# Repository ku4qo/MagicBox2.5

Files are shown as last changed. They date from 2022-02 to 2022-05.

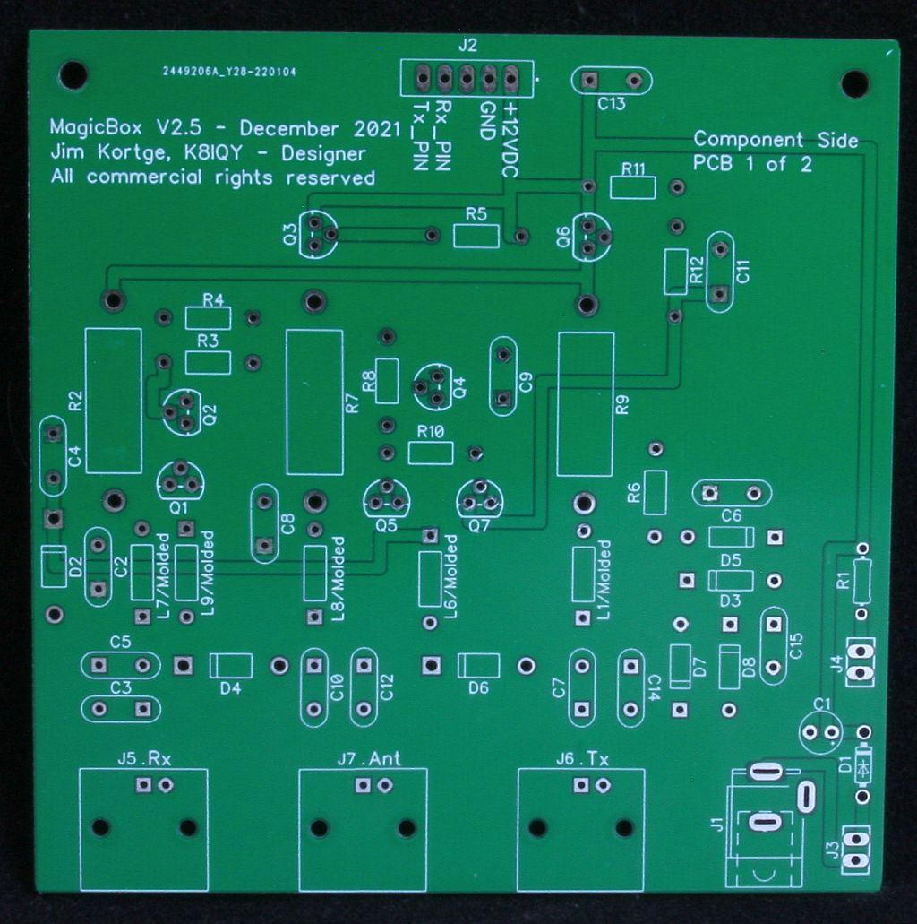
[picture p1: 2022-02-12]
images/MagicBoxV2.5-PCB1-1024pix.jpg

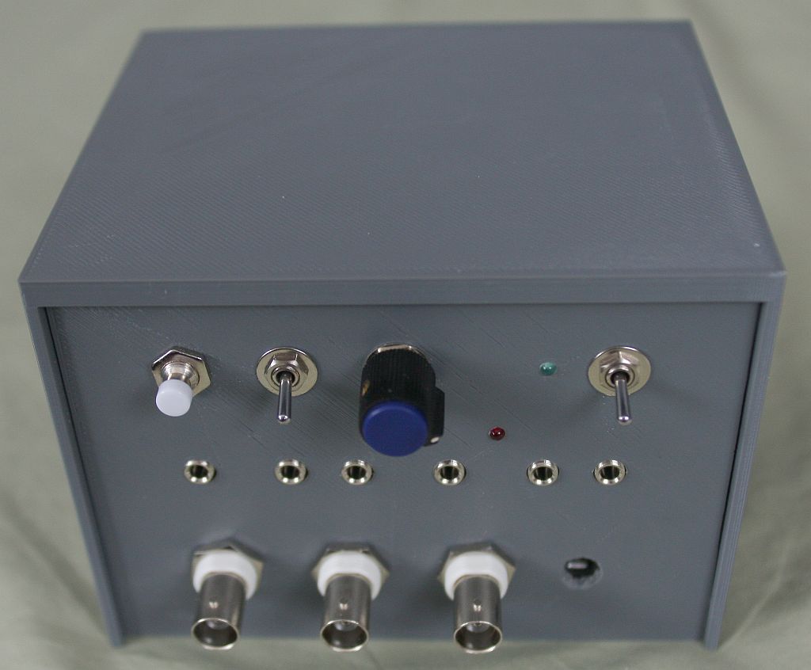
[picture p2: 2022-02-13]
images/MagicBoxV2.5_Front_1024pix.jpg

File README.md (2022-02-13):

# MagicBox2.5
Repo for software and hardware for the MagicBox 2.5 Tx/Rx interface 

The K8IQY/KU4QO MagicBox V2.5, is an updated version of the project
designed by K8IQY in 2013 and kitted by the 4 State QRP group. In the prior
version, the MagicBox could be used to connect a receiver and a transmitter
together to operate as a transceiver, with all of the RF switching and Audio Muting
handled by the MagicBox. It used a programmed microprocessor to control the
functions within the box.
The updated version provides all of the RF Switching and Audio Muting
functionality of the original, along with addition of an internal, speed adjustable,
CW Keyer, power control for transmitters requiring an external power source to be
switched, such as a Tuna Tin 2, and a redesign of the PIN diode RF Switching
circuitry to handle higher transmitter power levels. This version should handle
transmitters below 20 watts, with very low loss.

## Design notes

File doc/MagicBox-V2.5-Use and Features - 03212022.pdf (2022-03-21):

### K8IQY/KU4QO MagicBox V2.5 - Use and Features

### Jim Kortge, K8IQY Mike Maiorana, KU4QO

The K8IQY/KU4QO MagicBox V2.5, is an updated version of the project designed by K8IQY in 2013 and kitted by the 4 State QRP group. In the prior version, the MagicBox could be used to connect a receiver and a transmitter together to operate as a transceiver, with all of the RF switching and Audio Muting handled by the MagicBox. It used a programmed microprocessor to control the functions within the box.

The updated version provides all of the RF Switching and Audio Muting functionality of the original, along with addition of an internal, speed adjustable, CW Keyer, power control for transmitters requiring an external power source to be switched, such as a Tuna Tin 2, and a redesign of the PIN diode RF Switching circuitry to handle higher transmitter power levels. This version has been tested up to 20 watts, with very low loss.

Two printed circuit boards are employed in this version. The first one contains the power conditioning circuitry for the system, the PIN diode RF Switching circuitry for both the connected transmitter and receiver, and connections to the second printed circuit board. On the second board is where the system control microprocessor lives, the keying circuits for both negative (ground to transmit) and positive (source keyed) powered transmitters, and the receiver audio muting and side tone injection circuits. Unlike the previous version, the microprocessor in this version is an Arduino Nano (or clone) that is programmed by the builder (using the Arduino IDE) and the underlying control code can be modified to implement desired changes or additional functionality.

All of the documentation lives on GitHub, allowing anyone to procure printed circuit boards using the supplied Gerber files, have full access to the control software, and have access to the design’s schematic diagrams, bill of materials, and even suggested sources for the parts used.

“As built” Prototype Specifications:

Receiving
Antenna port to receive port loss: ~0.25 dB maximum
Receive port to transmit port isolation: -40 to -20 dB, frequency dependent

Transmitting
Transmit port to antenna port loss: ~0.25 dB maximum
Transmit port to receive port isolation: -70 to -50 dB, frequency dependent

Transmitter power limit – Tested at 20 Watts CW for 10 seconds, 10 Watts for 1 minute

Keyer
QSK and SemiQSK operation, user selected by internal jumper
Keying speeds from 5 to 35 WPM, user adjustable
via a speed set potentiometer
Straight key operation below 5 WPM

Keying of transmitters requiring grounding of key line, up to 100 volts
Keying of transmitters requiring power to be applied up to 48 volts and 2 amperes

Audio
Receive audio port to speaker port isolation: ~90+ dB
Side tone injection (level adjustable) into receive audio chain during transmit “Spot” function to zero receiver to transmitter frequency

Power Requirements (12 volt supply)
Receiving - 110 milliamperes
Transmitting - 160 milliamperes

How to use the MagicBox V2.5

This is a short discussion highlighting the features of the MagicBox V2.5 and how to hook it up to your receiver and transmitter.

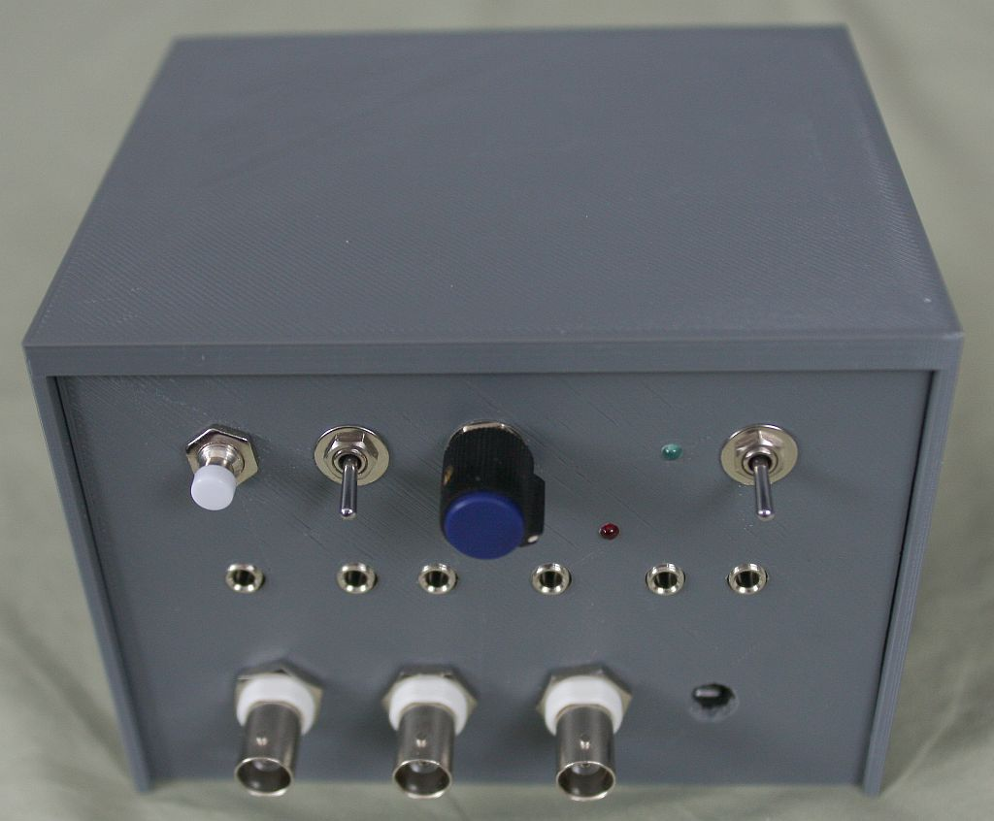
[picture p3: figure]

Starting at the lower left of this photo, the 1st BNC connector is the antenna input to your receiver. The 2nd BNC connector is where you connect your antenna. Lastly, the 3rd BNC connector goes to the output of your transmitter. When in “receive mode”, the center antenna connector is connected to the leftmost BNC, supplying signals to your receiver. When in “transmit mode”, the leftmost BNC is disconnected from the antenna, and shorted to ground, and the rightmost BNC is connected through to the center BNC, so that your transmitter is connected to your antenna. 1N4007 diodes are used as PIN diodes to do that signal steering, and their sequencing is done by the Arduino Nano

Figure 1: MagicBox V2.5 Font Panel board. Power to the system (12 to 13.8 volts DC) connects to the 2.1mm X 5.5mm power connector to the right of the BNC connectors.

The next row of connectors, above the BNCs, are all 1/8 inch, stereo jacks used for external signals, both inputs and outputs. The 1st of these on the left is the input connector for your paddle, or straight key. If using a paddle, the tip is “DIT”, the ring is “DAH”, and the sleeve is the common or ground. Either the tip or ring can be used for a straight key along with the ground.

The next two connectors are used for receive audio control. Audio FROM your receiver is connected to the leftmost of this pair, with the tip being the “HOT” lead and the ring being the ground. Audio TO your speaker or headphones connects to the rightmost of this pair. The “HOT” lead of your speaker goes to the Tip and the ground goes to the ring. Stereo headphones plug in directly. Note: the barrels of these two connectors can not be grounded. If mounting the MagicBox in a metal box, shrink tubing should be placed on the barrel of each of these two connectors. A non-conducting, 3D printed box is suggested.

The next 3 connectors are for keying your transmitter. If your transmitter is keyed by grounding a line, such as a “Keyline” in a solid state transmitter, or an older cathode keyed rig, where the “Keyline” has a positive voltage on it and needs to be grounded to key the transmitter “ON”, this is the connector to use. The tip is the “HOT” lead with the sleeve being the ground.

If you are using a transmitter, like a Tuna Tin Two, where the transmitter is keyed by keying the supply line, use the next pair of connectors. Connect the power supply for the transmitter to the right most of this pair, with the tip being the “HOT” lead, and the sleeve being the ground. Keyed voltage to your transmitter is available from the leftmost connector of this pair. The tip is the “HOT” lead and the ground is on the sleeve.

The red LED between the 4th and 5th connector lights when the transmitter is keyed, regardless of the keying setup used, as detailed above.

The leftmost push button on the upper level has two functions. With a “short press” a readout of the current CW speed is sent to the audio chain; a “long press”, turns on the transmitter for 10 seconds for “tune up”. A second push while the “tune up” function is engaged, terminates that function. Next is a SPST toggle switch used to implement the spotting function, where audio from the muted receiver is selectively mixed with the system generated side tone so that the receiver and transmitter can be set to the same frequency.

Next is a potentiometer, used to set the CW speed. When the potentiometer is set below 5 WPM, straignt key mode is automaticallyenabled.

A green LED is used to indicate when power is applied to the system, and to the right of it is a SPST toggle switch used to turn on – turn off system power.

All of the connections described are clearly shown on the schematics and are labeled on the two PC Boards used in this system. Some study of these resources is suggested for a complete understanding of how the system functions.

Miscellanous Parts
Below are some sources that I used for the parts in this prototype build. They may or may not be available, as parts on Amazon come and go.

Spacers
<https://www.amazon.com/gp/product/B06Y5TJXY1/ref=ppx_yo_dt_b_asin_title_o05_s00?ie=UTF8&psc=1> (https://www.amazon.com/gp/product/B06Y5TJXY1/ref=ppx_yo_dt_b_asin_title_o05_s00?ie=UTF8&psc=1)

This photo shows how spacers in this set are used.

Arduino Nano Clone

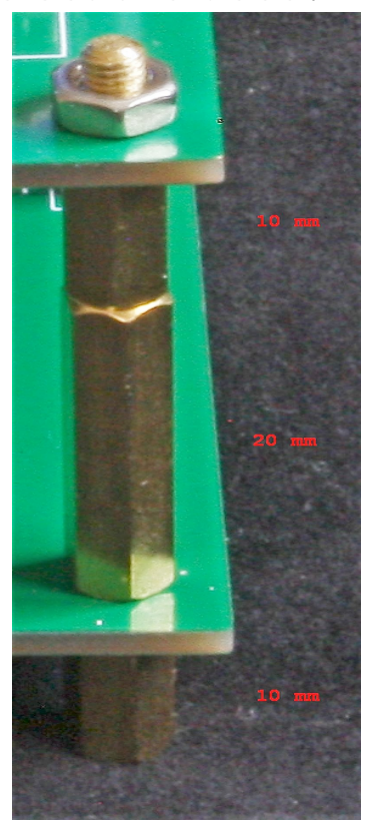
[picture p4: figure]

<https://www.amazon.com/gp/product/B0713XK923/ref=ppx_yo_dt_b_asin_title_o04_s00?ie=UTF8&psc=1> (https://www.amazon.com/gp/product/B0713XK923/ref=ppx_yo_dt_b_asin_title_o04_s00?ie=UTF8&psc=1)

Dupont Connectors (10 cm, Female-Female) <https://www.amazon.com/gp/product/B07GD312VG/ref=ppx_yo_dt_b_asin_title_o09_s00?ie=UTF8&th=1> (https://www.amazon.com/gp/product/B07GD312VG/ref=ppx_yo_dt_b_asin_title_o09_s00?ie=UTF8&th=1)

Case 3D Printing Filament
<https://www.amazon.com/gp/product/B08BXLQ26X/ref=ppx_yo_dt_b_asin_title_o00_s00?ie=UTF8&psc=1> (https://www.amazon.com/gp/product/B08BXLQ26X/ref=ppx_yo_dt_b_asin_title_o00_s00?ie=UTF8&psc=1)

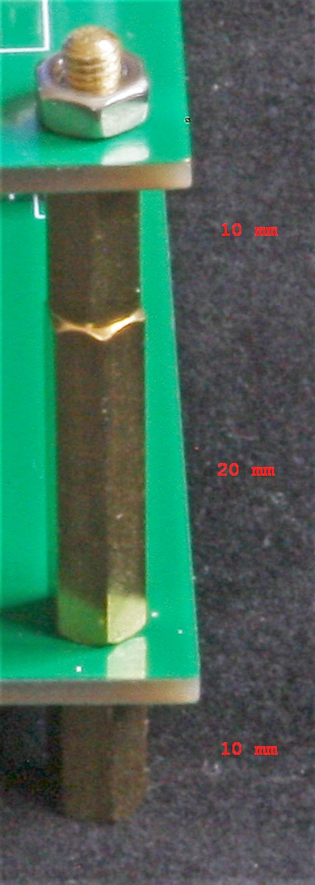
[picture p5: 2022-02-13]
images/Spacers-edited.jpg

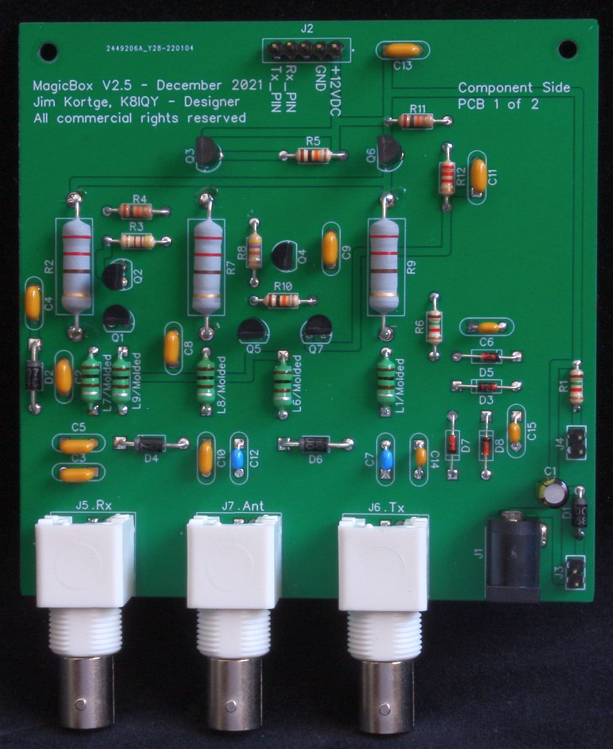
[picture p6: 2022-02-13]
images/MagicBoxV2.5-PCB1_Stuffed-1024pix.jpg

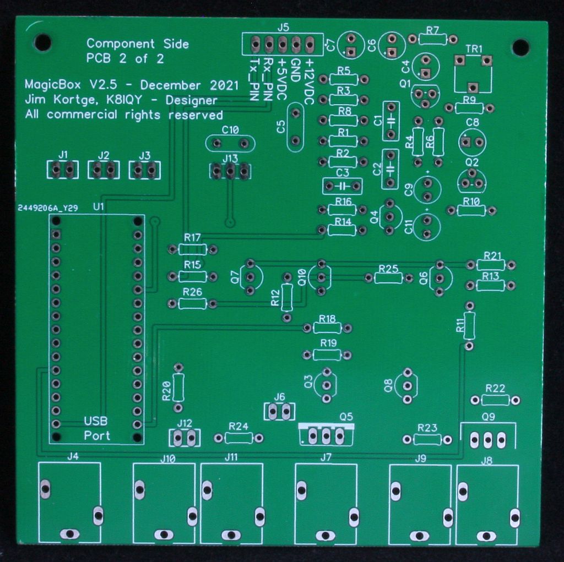
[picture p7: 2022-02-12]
images/MagicBoxV2.5-PCB2-1024pix.jpg

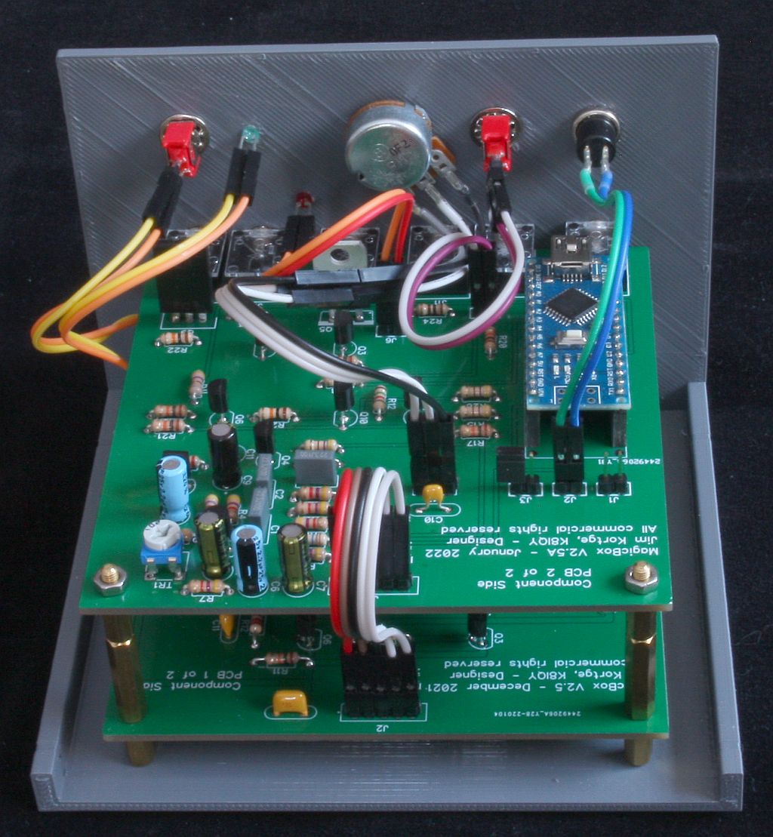
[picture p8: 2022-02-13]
images/MagicBoxV2.X_Rear_1024pix.jpg

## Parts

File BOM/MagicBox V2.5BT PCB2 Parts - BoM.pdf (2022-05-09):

# RefDes | Quantity Value | Name | Manufacturer/Source | Part Number

1 C10 | 1 | 0.01uF | MLCC | Tayda Electronics | A-1366
2 C1, C2, C3 | 3 | 0.022uF | Mylar Capacitor | Tayda Electronics | A-4107
3 C5 | 1 | 0.1uF | MLCC | Tayda Electronics | A-214
4 C6, C8 | 2 | 2.2uF | 25 VDC Electrolytic Tayda Electronics | A-4510
5 C4, C7, C9 | 3 | 47uF | 25 VDC Electrolytic Tayda Electronics | A-5713
6 J12 | 1 | Spot | 2-pin header | Tayda Electronics | A-4662
7 J1 | 1 | Spd_Up | 2-pin header | Tayda Electronics | Part of above
8 J2 | 1 | Spd_Dwn | 2-pin header | Tayda Electronics | Part of above
9 J3 | 1 | Non-QSK | 2-pin header | Tayda Electronics | Part of above
10 J6 | 1 | Tx-LED | 2-pin header | Tayda Electronics | Part of above
11 J13 | 1 | Speed Pot | 3-pin header | Tayda Electronics | Part of above
12 J5 | 1 | Interconnect | 5-Pin Header | Tayda Electronics | Part of above
13 J4 | 1 | Paddle | PCB Phone Jack | Tayda Electronics | A-069
14 J7 | 1 | TxKey_GND | PCB Phone Jack | Tayda Electronics | A-069
15 J8 | 1 | TxKey_PWR_IN | PCB Phone Jack | Tayda Electronics | A-069
16 J9 | 1 | TxKey_PWR_OUT PCB Phone Jack | Tayda Electronics | A-069
17 J10 | 1 | Rx_Audio_In | PCB Phone Jack | Tayda Electronics | A-069
18 J11 | 1 | Spkr/Phones | PCB Phone Jack | Tayda Electronics | A-069
19 Q1, Q2 | 2 | PN2222A | NPN Transistor | Tayda Electronics | A-096
20 Q3, Q4, Q6, Q7, Q8, Q10 | 6 | BS170 | BS170 | Tayda Electronics | A-096
21 Q5 | 1 | IRF510 | N-MOSFET | Tayda Electronics | A-088
22 Q9 | 1 | FQPF11P06 | P-MOSFET | Tayda Electronics (IRF9640 Sub) | A-084
23 R24 | 1 | 100 | 1/4 Watt Resistor | Tayda Electronics | A-2245
24 R10 | 1 | 220 | 1/4 Watt Resistor | Tayda Electronics | A-2246
25 R6, R11, R14, R15, R18, R26 | 6 | 470 | 1/4 Watt Resistor | Tayda Electronics | A-2247
26 R12 | 1 | 1.5K | 1/4 Watt Resistor | Tayda Electronics | A-2202
27 R1, R2, R4, R5, R7, R8, R9 | 7 | 4.7K | 1/4 Watt Resistor | Tayda Electronics | A-2310
28 R13, R16, R17, R19, R20, R21, R22, R23, R25 9 | 10K | 1/4 Watt Resistor | Tayda Electronics | A-2203
29 R3 | 1 | 36K | 1/4 Watt Resistor | Tayda Electronics | A-2773
33 TR1 | 1 | 1K | 6 mm trimmer | Tayda Electronics | A-2509
34 External J13 connection | 1 | 1K | 1-turn potentiometer Tayda Electronics | A-4870
35 U1 | 1 | Arduino Nano V3.X A000005 | Tayda Electronics (Amazon - ELEGOO Nano Board) A-2864
36 Misc part | 1 | Arduino mounting | 40-pin female header Tayda Electronics | A-196
37 Misc part | 2 | Speed select switch SPST-momentary | Tayda Electronics | A-5051
38 C11 | 1 | Value as needed | 25 VDC Electrolytic 2.2uF suggested value

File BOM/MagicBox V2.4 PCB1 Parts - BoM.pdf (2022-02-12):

# RefDes | Quantity Value | Name | Manufacturer/Source | Part Number

1 C14 | 1 | 100pF | NP0 Ceramic Capacitor Mouser | 810-FA28NP02A101JNU6
2 C6, C15 | 2 | 0.01uF | MLCC | Tayda Electronics | A-1366
3 C2, C3, C4, C5, C8, C9, C10, C11, C13 | 9 | 0.1uF | MLCC | Tayda Electronics | A-5705
4 C7, C12 | 2 | 1uF | X7S Ceramic Capacitor Mouser | 810-FG24X7S2A105KRT0
5 C1 | 1 | 47uF | 25 VDC Electrolytic | Tayda Electronics | A-5713
6 D1 | 1 | 1N5817/8 | Schottky Diode | Tayda Electronics | A-159
7 D2, D4, D6 | 3 | 1N4007 | Si Diode | Tayda Electronics | A-155
8 D3, D5, D7, D8 | 4 | 1N914 | Si Diode | Tayda Electronics | A-615
9 J1 | 1 | 12 Volts | Power Jack 2.1mm | Tayda Electronics | A-4118
10 J2 | 1 | Interconnect 5-Pin Header | Tayda Electronics | A-197
11 J3 | 1 | Pwr Switch | 2-pin header | Tayda Electronics | Part of A-197
12 J4 | 1 | Pwr LED | 2-pin header | Tayda Electronics | Part of A-197
13 J5 | 1 | Rx_Input | BNC Connector | TE Connectivity (Mouser) 571-2269901
14 J6 | 1 | Tx_Input | BNC Connector | TE Connectivity (Mouser) 571-2269901
15 J7 | 1 | Antenna | BNC Connector | TE Connectivity (Mouser) 571-2269901
16 L1/Molded, L6/Molded, L7/Molded, L8/Molded, L9/Molded 5 | 100uH | Molded Inductor | Tayda Electronics | A-193
17 Q1, Q2, Q4, Q5, Q7 | 5 | BS170 | MOSFET | Tayda Electronics | A-096
18 Q3, Q6 | 2 | PN2907A | PNP Transistor | Tayda Electronics | A-108
19 R2, R7, R9 | 3 | 220/2W | Metal Film Resistor | Tayda Electronics | A-2538
20 R3, R8 | 2 | 470 | 1/4 Watt Resistor | Tayda Electronics | A-2247
21 R1, R6 | 2 | 1.5k | 1/4 Watt Resistor | Tayda Electronics | A-2202
22 R12 | 1 | 2.2k | 1/4 Watt Resistor | Tayda Electronics | A-2341
23 R4, R5, R10, R11 | 4 | 10k | 1/4 Watt Resistor | Tayda Electronics | A-2203
24 Misc. part | 6 | 2-56 X 1/4 | Self Tapping Screw | McMaster-Carr | 94629A110

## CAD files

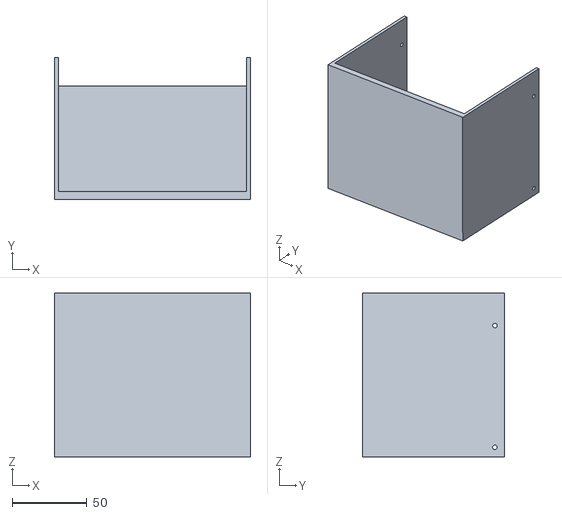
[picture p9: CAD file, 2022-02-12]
case/MagicBox-Cover-V5_K8IQY.stl
130.8 x 94.7 x 109.2

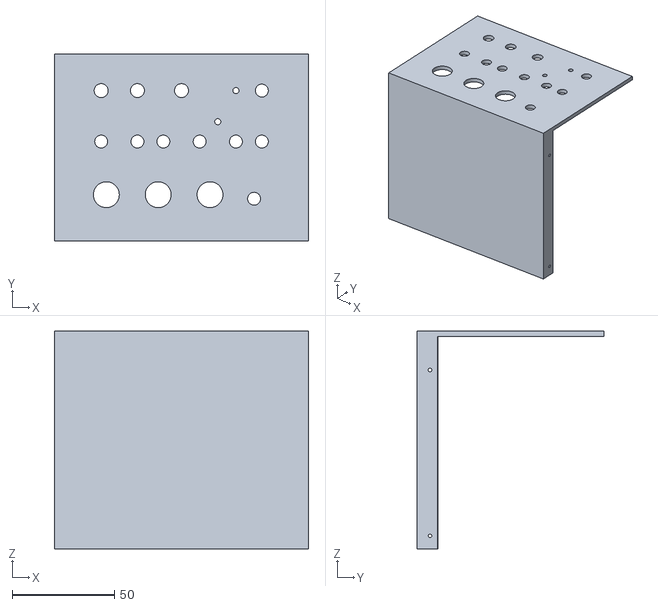
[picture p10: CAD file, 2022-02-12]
case/MagicBox-FrontPanel-V5_K8IQY.stl
124.5 x 91.6 x 106.7

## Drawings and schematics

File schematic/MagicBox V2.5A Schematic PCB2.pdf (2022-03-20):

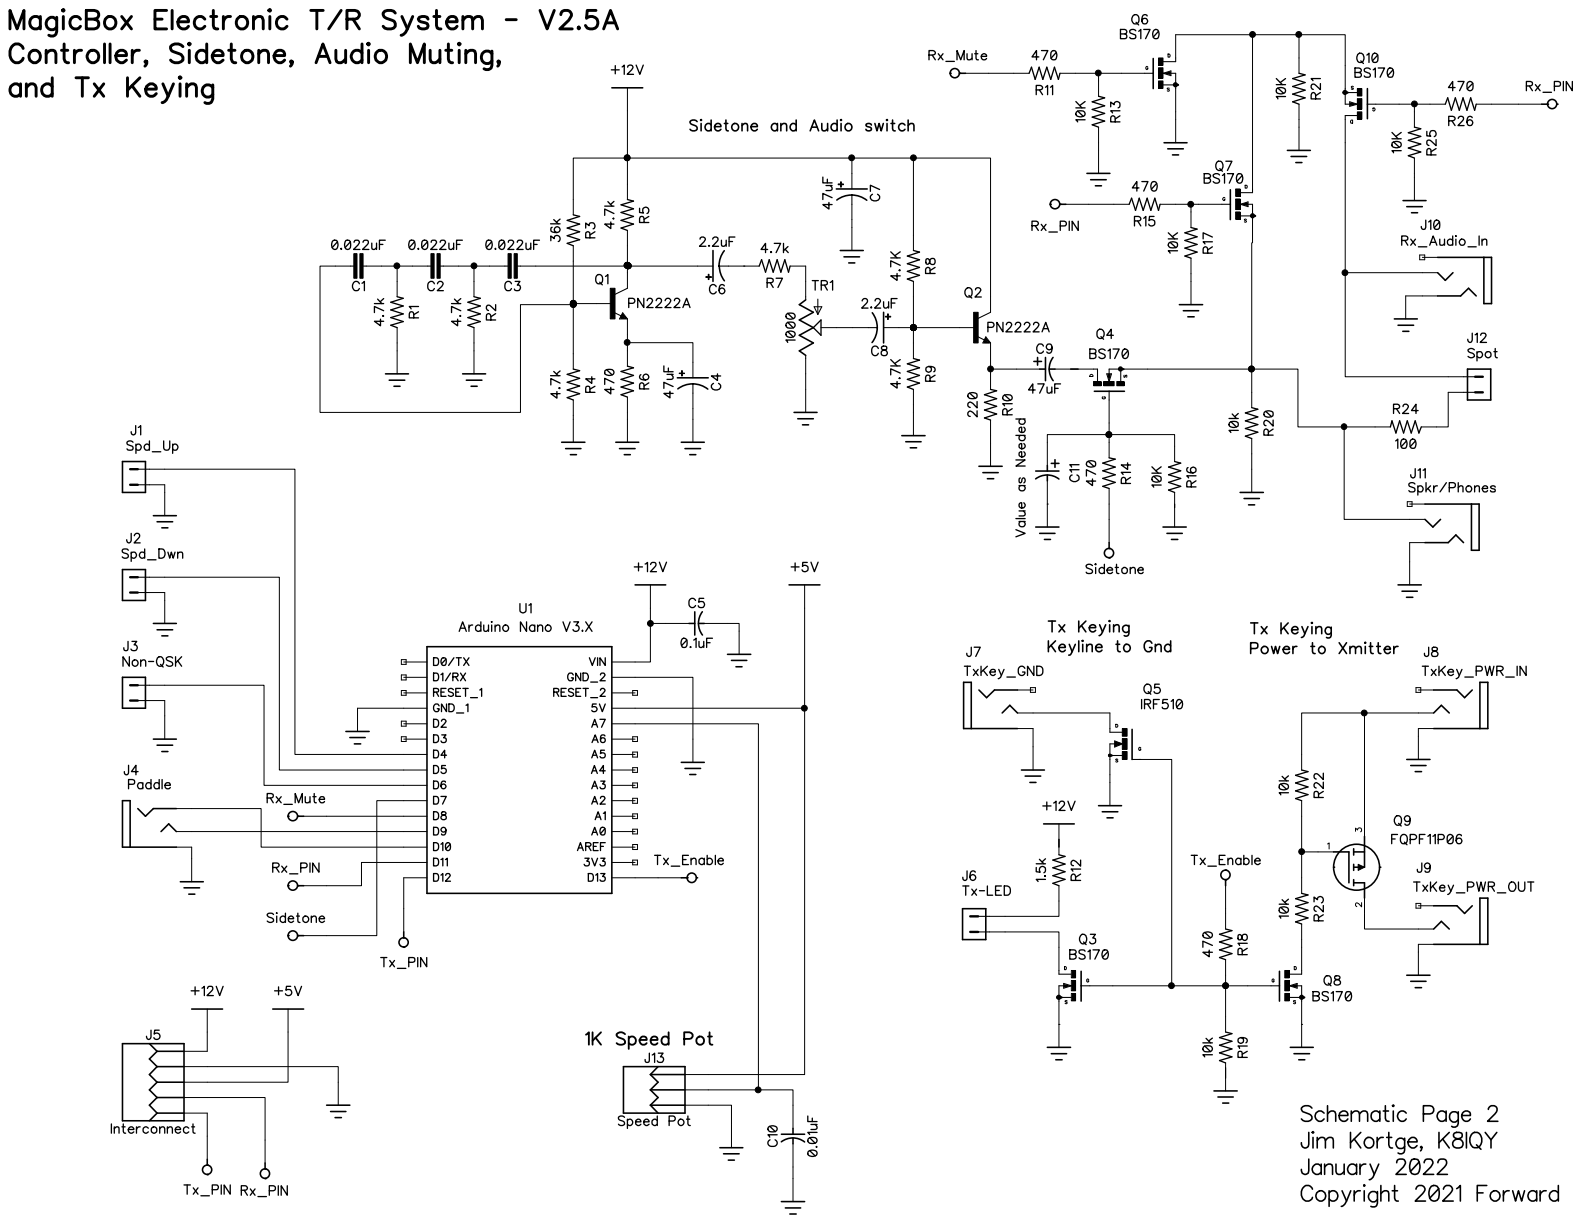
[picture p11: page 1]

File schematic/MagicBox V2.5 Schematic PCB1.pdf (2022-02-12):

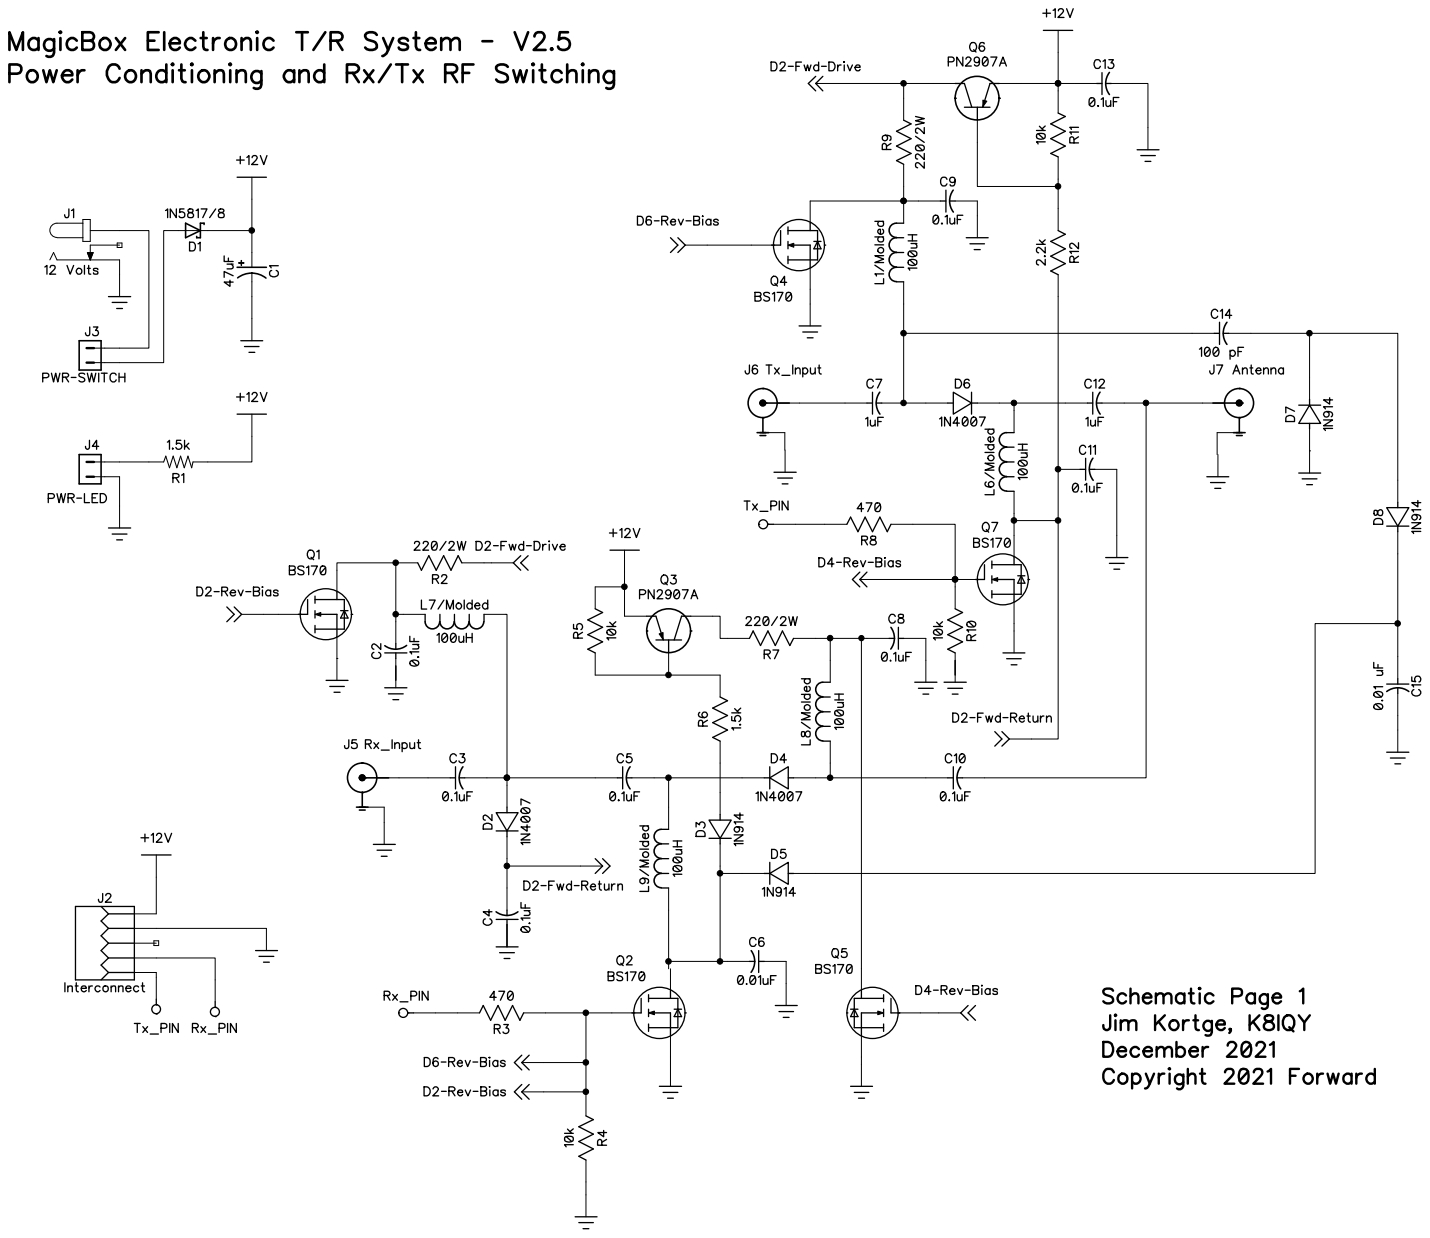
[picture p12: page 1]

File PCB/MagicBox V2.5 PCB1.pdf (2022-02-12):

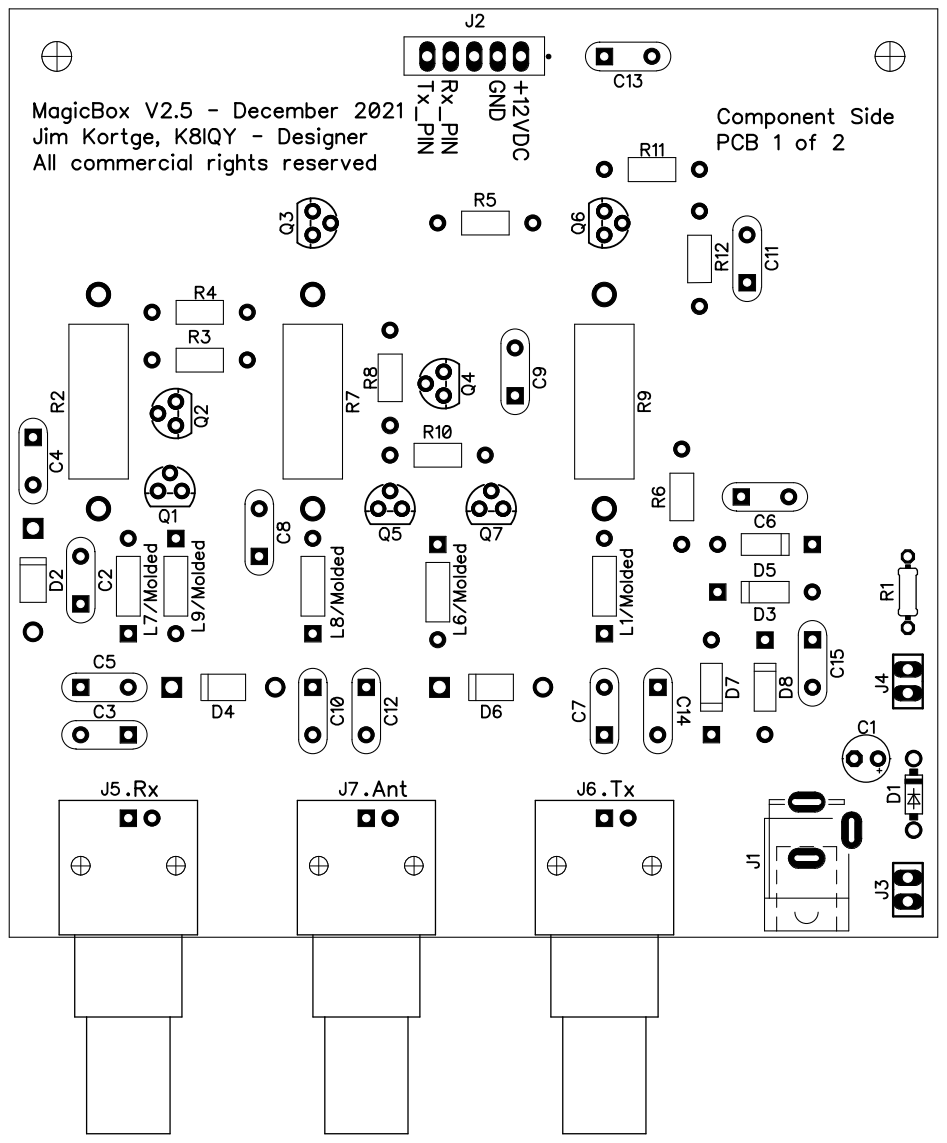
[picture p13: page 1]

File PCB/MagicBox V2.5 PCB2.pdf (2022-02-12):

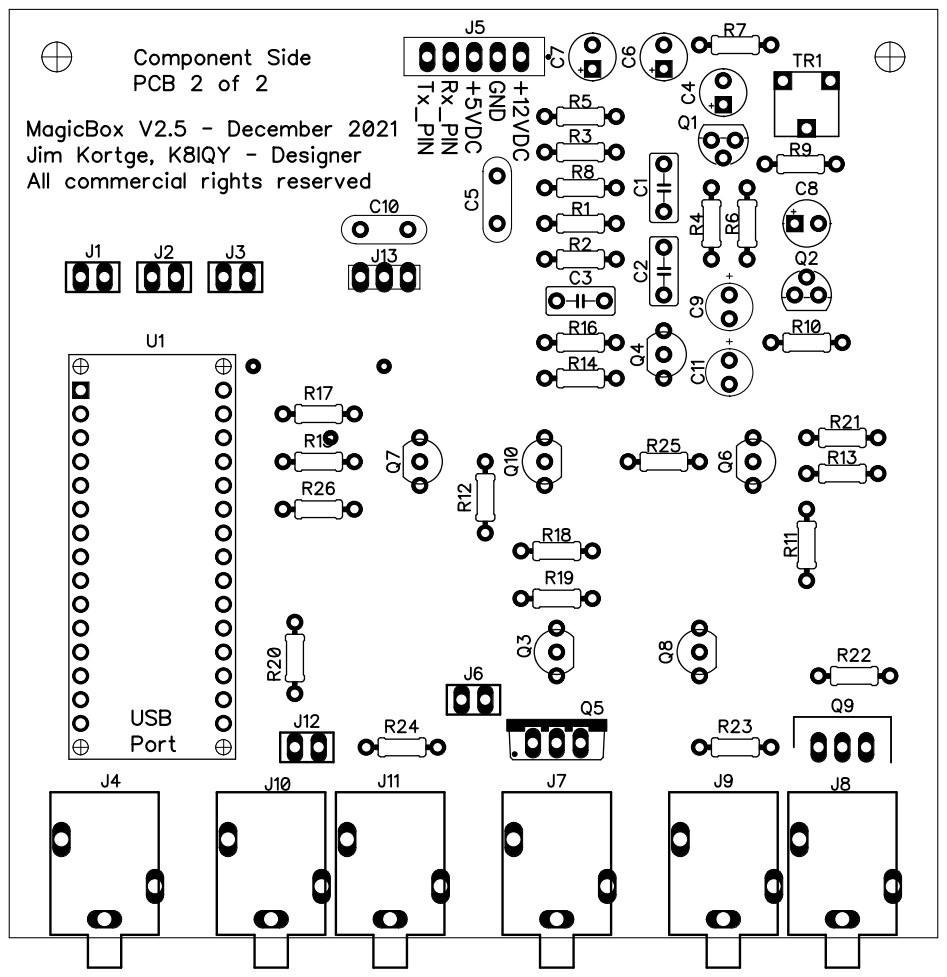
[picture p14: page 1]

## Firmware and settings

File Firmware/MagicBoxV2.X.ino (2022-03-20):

/* Firmware for MagicBox V2.X - 03/20/2022
  by Jim Kortge K8IQY and Mike Maiorana KU4QO
  Control button (J2 on PCB rev 2.5A):
    quick press - announce current cw speed with the sidetone. Sent at current cw speed.
    long press  - tune mode turns on transmitter for 10 seconds. Cancel by pressing again.
  Non-QSK jumper disables full QSK and adds a timer to revert to RX mode after last TX.
  10k pot with wiper connected to A7 adjusts cw speed from 0 (straight key) to 35wpm
*/
#define VERSION 03202022

//set up for control lines
#define BTN           5         //control button, momentary SPST, 0=closed
#define NON_QSK       6         //Non QSK header, open=QSK, closed=Non-QSK
#define SIDETONE      7         //Side tone signal control, 1=on
#define RX_MUTE       8         //Shunt switch in Rx audio path, 1=on
#define PADDLE_DIT    9         //Paddle dit contact, 0=closed
#define PADDLE_DAH    10        //Paddle dah contact, 0=closed 
#define RX_PIN        11        //Rx PIN diode path enable, 1=on, This line also controls the Rx audio path series switches
#define TX_PIN        12        //Tx PIN diode path enable, 1=on
#define TX_ENABLE     13        //Transmitter ON/OFF control line, 1=on
#define SPD_DIAL      A7        //Input from cw speed potentiometer

//keyercontrol flags
#define     DIT_L      0x01     // Dit latch
#define     DAH_L      0x02     // Dah latch
#define     DIT_PROC   0x04     // Dit is being processed
#define     PDLSWAP    0x08     // 0 for normal, 1 for swap
#define     IAMBICB    0x10     // 0 for Iambic A, 1 for Iambic B

//set up for keyer
enum KSTYPE {IDLE, CHK_DIT, CHK_DAH, KEYED_PREP, KEYED, INTER_ELEMENT };
unsigned long       ditTime;                       // No. milliseconds per dit
unsigned char       keyerControl;
unsigned char       keyerState = IDLE;

int wpm;                                   //holds cw speed
int a_wpm;                                 //analog reading of cw speed dial
int a_wpm_save = 99;                            //holds last dial cw reading
bool straight_key = false;                 // straight key enable
bool sk_on = false;                        //tracking straight key transmit status
static long ktimer;                        // timer variable for keyer

//input switches Finite State Machines
unsigned long t_sd = 0;                   //timer for control switch
const unsigned long bounce_delay = 10;    //debounce timer in milliseconds
const unsigned long double_delay = 200;   //double-press timeout in milliseconds
const unsigned long hold_delay = 500;     //long-press timeout in milliseconds
const unsigned long qsk_timeout = 1500;   //RX timeout for non-QSK mode in milliseconds
const unsigned long tune_timeout = 10000; //tune mode timer in milliseconds
unsigned long qsk_timer;                  //variable holds non-QSK mode timer
bool qsk_enable;                          //flag to track QSK mode. True is full QSK on.
//enumeration for button state machines 
enum FSM {RST, WAIT, ARM, DEBOUNCE, LIFT, SHORT, ARMDBL, CHKDBL, DBL, LONG, RELEASE, CANCEL, FIN, FIN_WAIT};
FSM state_sd;                             //new variable of enumeration type FSM for control switch

const int morse[10] {                     //array contains data to send numbers 0-9 in morse. 1=dit, 0=dah
0b00000,
0b00001,
0b00011,
0b00111,
0b01111,
0b11111,
0b11110,
0b11100,
0b11000,
0b10000
};

int int_wpm;                              //integers used in announce routine to send CW speed in morse to sidetone
int int_wpm_l;

void setup () {
  //initialize the I/O pins
  pinMode(BTN, INPUT_PULLUP);
  pinMode(NON_QSK, INPUT_PULLUP);
  pinMode(PADDLE_DIT, INPUT_PULLUP);
  pinMode(PADDLE_DAH, INPUT_PULLUP);

  pinMode(TX_ENABLE, OUTPUT);     //this output controls the transmitter
  digitalWrite(TX_ENABLE, LOW);   //make sure it is off
  pinMode(TX_PIN, OUTPUT);        //Tx PIN switch control
  digitalWrite(TX_PIN, LOW);      //Initialize low, disconnect transmitter from antenna
  pinMode(RX_PIN, OUTPUT);        //Rx PIN switch control
  digitalWrite(RX_PIN, HIGH);     //Initialize high, connects antenna to receiver
  pinMode(RX_MUTE,  OUTPUT);      //Rx audio mute line, shunt switch
  digitalWrite(RX_MUTE, LOW);     //Initialize low, so shunt switch is open
  pinMode(SIDETONE, OUTPUT);      //Side tone control line
  digitalWrite(SIDETONE, LOW);    //Initial low, so tone off during receive

}

void loop()                                         //Main program loop
{

  a_wpm = analogRead(SPD_DIAL) >> 5;                //read potentiometer voltage and set keyer speed
  if (a_wpm != a_wpm_save ) {                       //process dial reading only when it changes
    a_wpm_save = a_wpm;                             //save last analog reading
    if ( a_wpm == 0 ) {
      straight_key=true;
      wpm=5;
      loadWPM(wpm);
    }
    else {
      wpm = a_wpm + 4;
      straight_key=false;
      loadWPM(wpm);
    }
  }
  
  qsk_enable=digitalRead(NON_QSK);                //read non-QSK jumper and set system mode
  
  //Routine to key system, either with keyer or straight key
  if (straight_key == false) check_keyer();      //call keyer or straight key code depending on mode
    else check_sk();

  fsm_sd();                                       //run the FSM for the control button
  if (state_sd == SHORT)  {                      //button press FSM
    announce();
  }
  
  if (state_sd == LONG) xmit_on();              // tune function if down button long press
  if (state_sd == FIN) xmit_off();              // cancel tune function

  if (qsk_enable == false) {                    // check qsk timer in non-QSK mode. Recover RX when timer expires.
    if (((millis() - qsk_timer) > qsk_timeout ) && (digitalRead(RX_MUTE) == HIGH)) rx_on();
  }
}

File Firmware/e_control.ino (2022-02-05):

//Transmit ON/OFF control

void xmit_on()                                //Routine to turn the transmitter ON
{
  digitalWrite(RX_MUTE, HIGH);          //Close Shunt switch to mute Rx
  delay(2);
  digitalWrite(RX_PIN, LOW);            //Disconnect Rx from antenna, open audio Rx series switches
  delay(5);
  digitalWrite(TX_PIN, HIGH);           //Connect Tx to antenna
  delay(2);
  digitalWrite(SIDETONE, HIGH);         //Turn on side tone
  delay(2);
  digitalWrite(TX_ENABLE, HIGH);        //Turn on Tx
  if (qsk_enable == false) qsk_timer = millis();    //kick the QSK timer in non-QSK mode
}

void xmit_off()                         //Routine to turn the transmitter OFF
{
  digitalWrite(SIDETONE, LOW);          //Turn off side tone
  delay(2);
  digitalWrite(TX_ENABLE, LOW);         //Turn off Tx
  delay(5);
  if (qsk_enable == true) rx_on();      //recover Rx in QSK mode. Kick timer in non-QSK mode.
  else qsk_timer = millis();
}

void rx_on()                            //Routine to turn the receiver ON
{
  digitalWrite(TX_PIN, LOW);            //Disconnect Tx from antenna
  delay(2);
  digitalWrite(RX_PIN, HIGH);           //turn on Rx PIN diode switch
  delay(2);
  digitalWrite(RX_MUTE, LOW);           //Open shunt switch to unmute Rx audio
}

void quick_beep()                       //short sidetone beep for button feedback
{
    digitalWrite(SIDETONE, HIGH);
    delay(50);
    digitalWrite(SIDETONE, LOW);
}

void announce()                         //announce wpm with sidetone at current wpm setting
{
  if (straight_key == true) {           //in straight key mode, send morse S character
    //send S
    quick_beep();
    delay(50);
    quick_beep();
    delay(50);
    quick_beep();
  }
  else if (wpm >= 10) {                 //two character cw speed. Break up into to separate number for sending
    int_wpm = wpm / 10;
    int_wpm_l= wpm % 10;
    for (int bits = 0; bits < 5; bits++) {            //read one bit at a time and send dit or dah
      if (morse[int_wpm] & (1 << bits)) dit_tone();
        else dah_tone();
    }
    
    delay(ditTime);                     //intercharacter delay
    
    for (int bits = 0; bits < 5; bits++) {      //send lower number in CW
      if (morse[int_wpm_l] & (1 << bits)) dit_tone();
        else dah_tone();
    }
  }
    else {
      int_wpm = wpm;
      for (int bits = 0; bits < 5; bits++) {
      if (morse[int_wpm] & (1 << bits)) dit_tone();
        else dah_tone();
      }
    }
}

void dit_tone()                         //dit sidetone for cw speed announcement
{
    digitalWrite(SIDETONE, HIGH);
    delay(ditTime);
    //delay(120);                       //uncomment these and comment other delays for fixed cw speed announce
    digitalWrite(SIDETONE, LOW);
    delay(ditTime);
    //delay(120);
}

void dah_tone()                       //dah sidetone for cw speed announcement
{
    digitalWrite(SIDETONE, HIGH);
    delay(3 * ditTime);
    //delay(360);
    digitalWrite(SIDETONE, LOW);
    delay(ditTime);
    //delay(120);
}

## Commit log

2021-12-05 Add files via upload
    Fixed upper-limit code speed bug.
    [MagicBoxV2.X.ino, e_control.ino]
2021-12-07 Add files via upload
    Added ability to change cw speed with potentiometer. Cleaned up straight key mode entry and exit. Changed button steps to 5wpm
2022-02-05 Add files via upload
    removed up/down cw speed buttons. Cleaned up code.
2022-03-20 Add files via upload
    Audio chain fix
2022-03-20 Delete MagicBox V2.5 Schematic PCB2.pdf
    removed because of audio chain error
2022-03-20 Add files via upload
    Fixed straight-key startup bug
    [MagicBoxV2.X.ino]
